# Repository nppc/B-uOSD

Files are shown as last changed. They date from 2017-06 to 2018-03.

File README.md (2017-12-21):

# Battery voltage microOSD v1.2
Very small and simple OSD for monitoring Battery voltage. It is useful for AIO micro cameras, FPV helmet etc.

The PCB is very small. Can be ordered at OshPark: https://oshpark.com/shared_projects/nvOy0lBm
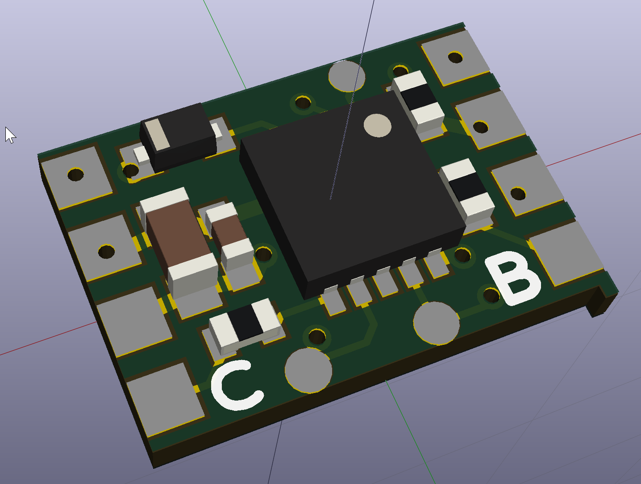
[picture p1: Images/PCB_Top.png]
Virtual PCB top

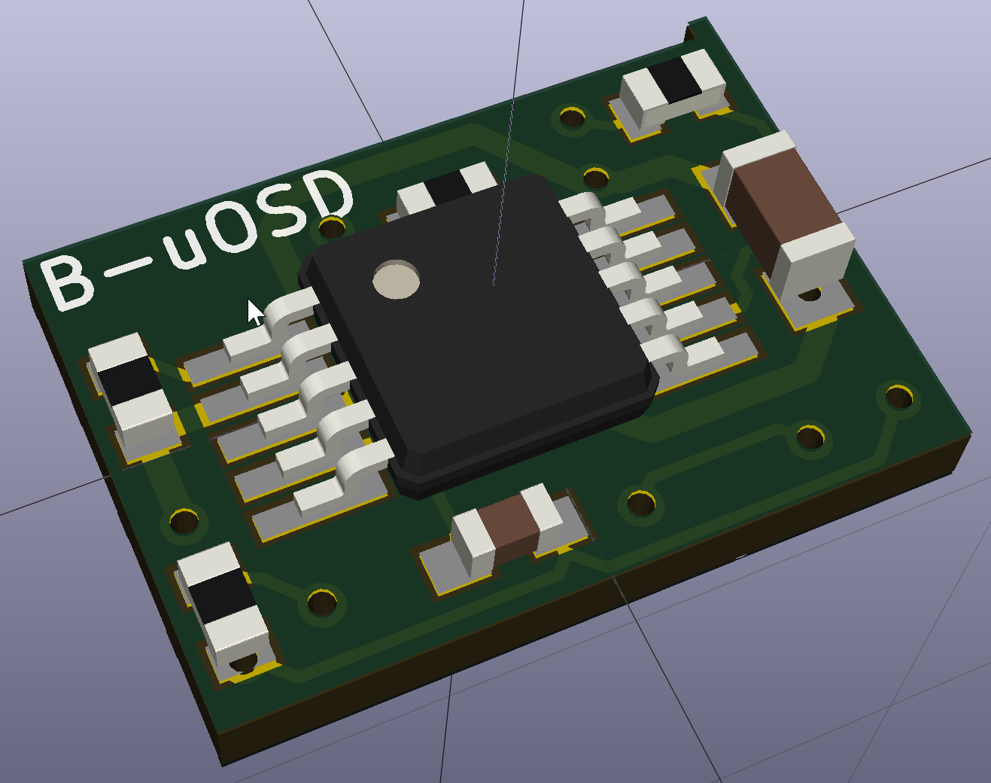
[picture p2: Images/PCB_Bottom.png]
Virtual PCB bottom


## Functionality
- Supports 1S-4S battery monitoring. (Changing onboard voltage divider can be extended for bigger batteries.)
- Adjustable text position.
- Shows current voltage and minimal detected voltage.
- Pilot name, Crosshair and timer.
- Voltage blinking if battery running low.
- Supply voltage 3.3-5.5v.
- Low supply current, no heat generation.
- It is very small size (8.8mm X 6mm).
- Virtually weights nothing.
- Configurable parameters via compiling.

It has minuses too.
- Due to small and slow mcu (no special mcu for signal generation) the OSD picture is not as stable as other bigger OSDs.
- No shadow around the symbols (not visible on white background). Planned it rhe future releases.

Discussion is here: https://www.rcgroups.com/forums/showthread.php?2985720-uOSD-World-smallest-micro-OSD

Some screenshots:
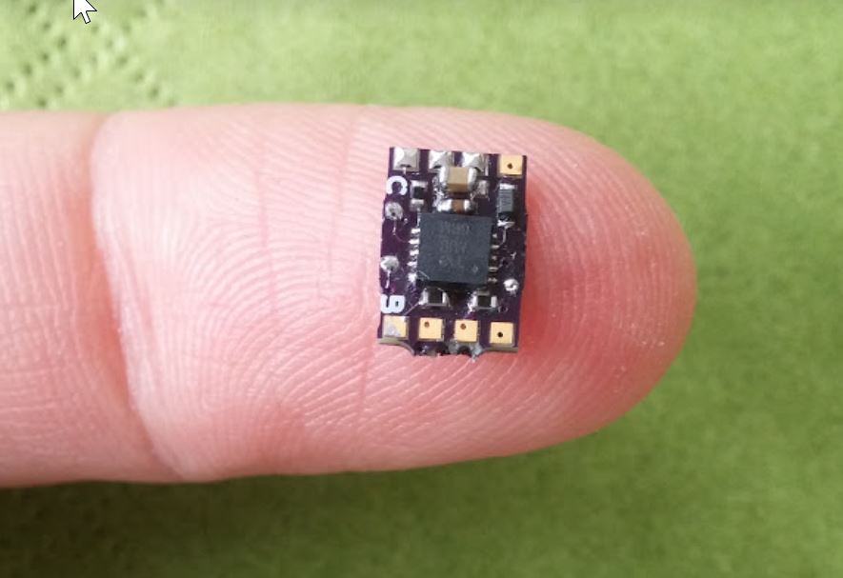
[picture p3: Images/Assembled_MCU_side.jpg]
Sample Double height

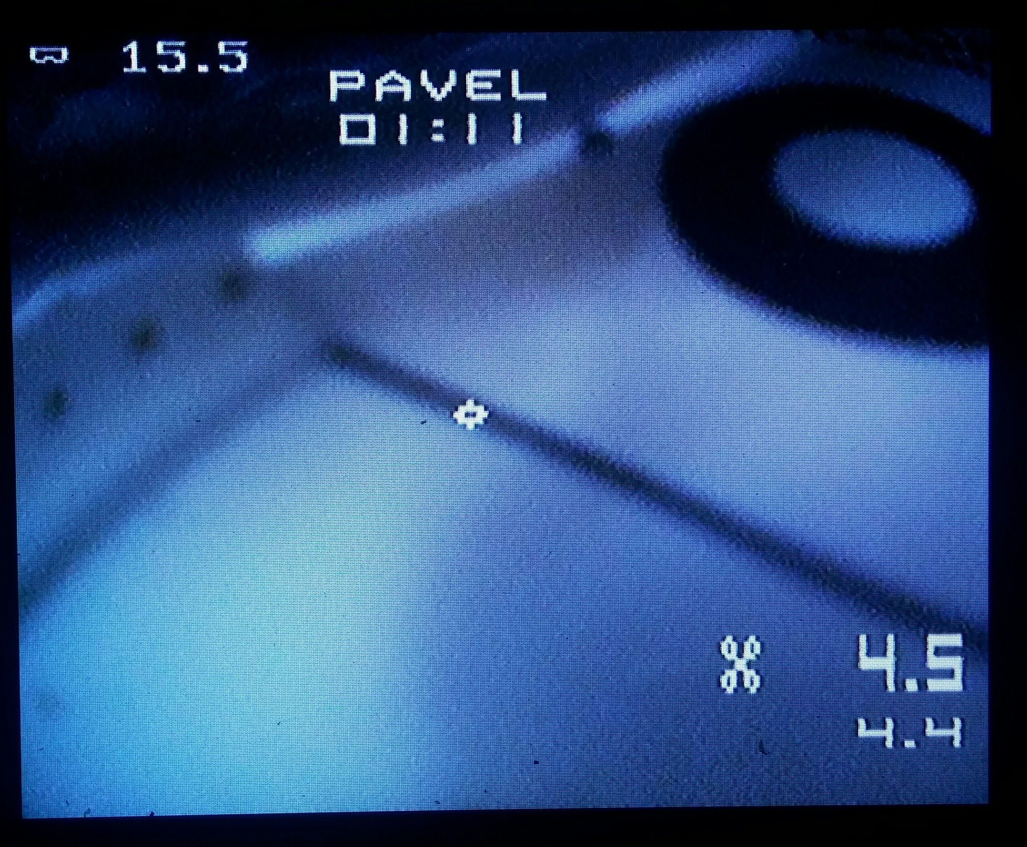
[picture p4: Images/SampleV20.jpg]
Sample V2.0


## Connection
There is many possibilities to use this OSD.
One example for 1S setup:
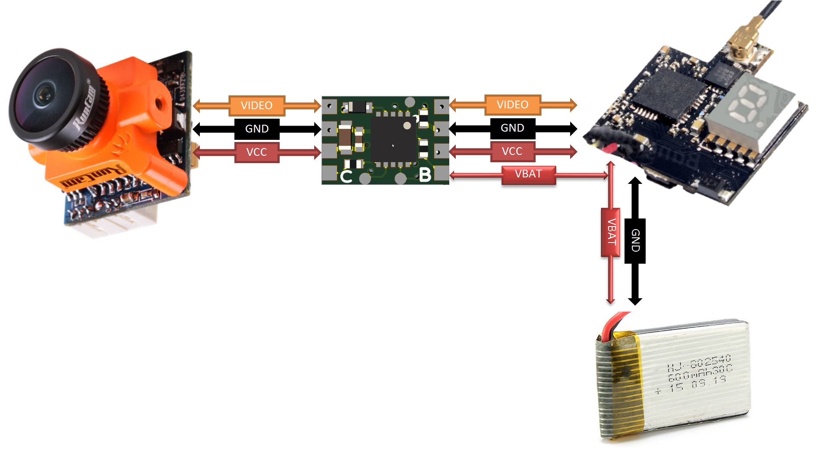
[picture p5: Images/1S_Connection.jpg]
Sample connection 1S


Another example for AIO combo camera/vtx 1S setup:
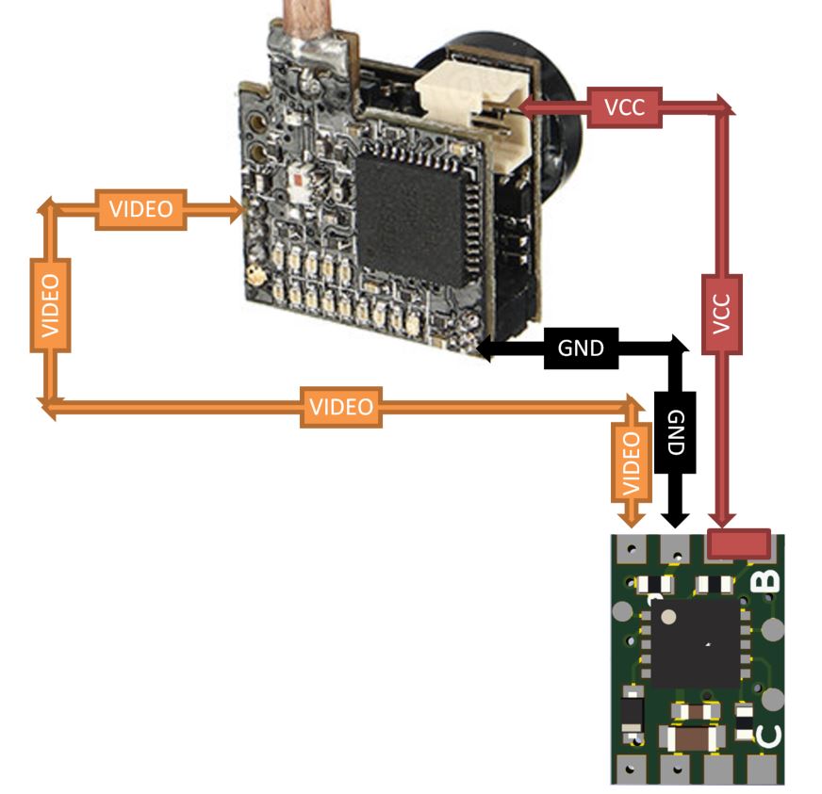
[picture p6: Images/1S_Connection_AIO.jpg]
Sample connection AIO 1S


## Compilation
To compile source files there is several options.
### Under Linux (even cheap OrangePi board will work)
Install `avra` and `git`
```
apt-get install avra git
```
Clone the project to any directory
```
git clone https://github.com/nppc/B-uOSD.git
```
Navigate to `Bin` directory
```
cd B-uOSD/Bin
```
And run `compile_linux.sh` script
```
./compile_linux.sh
```
Now you have .hex file.

### Under Windows
Project can be compiled with AVRASM2 (similar to avra on Linux) or with AVR Studio.

## Flashing
Use `avrdude` software and `USBASP` dongle for flashing microcontroller. 
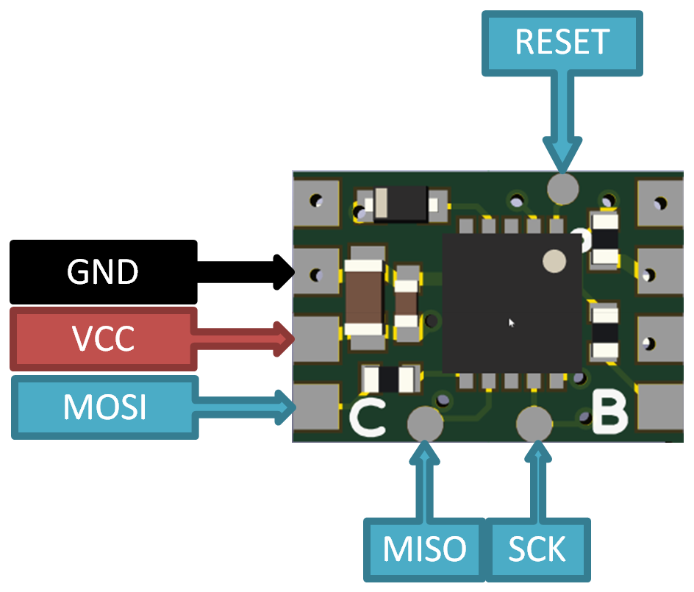
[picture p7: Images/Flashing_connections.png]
Connect for flashing

```
avrdude.exe -c usbasp -p t13 -P usb -B 4.0 -U flash:w:B-uOSD_vXX.hex:a
```

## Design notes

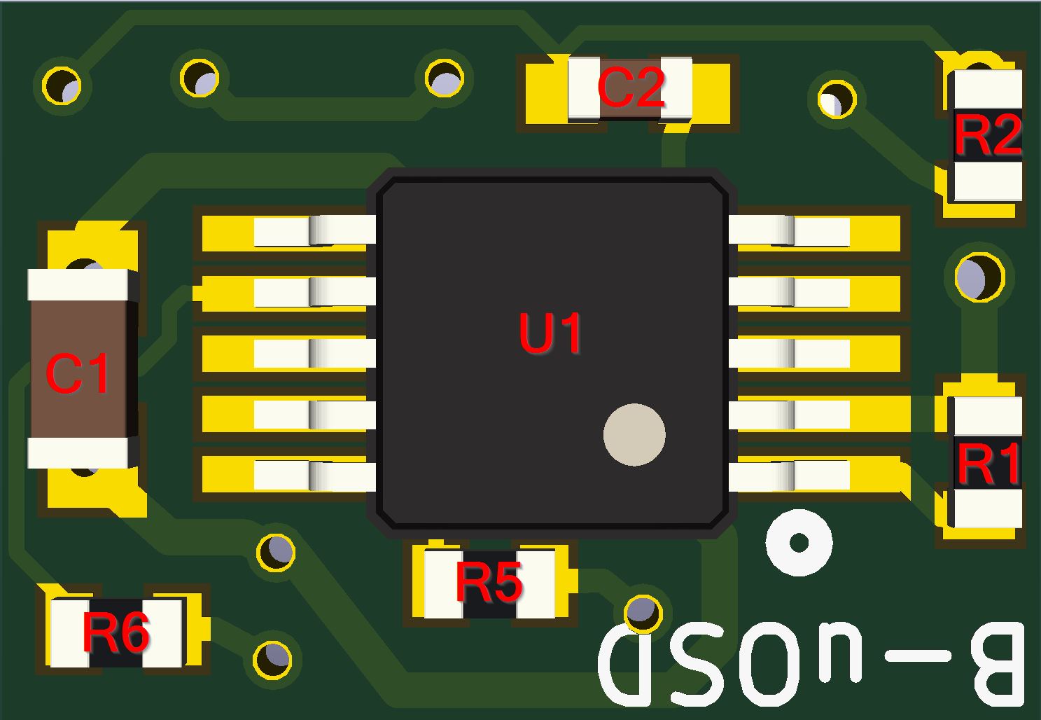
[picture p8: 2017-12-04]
Images/uOSD_V1_PCB2.jpg

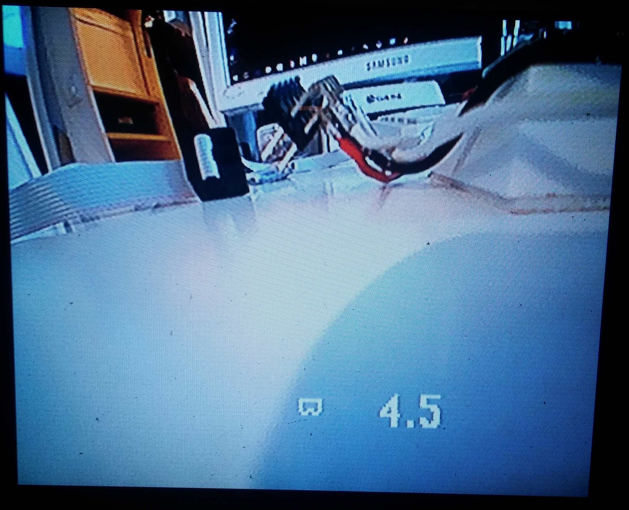
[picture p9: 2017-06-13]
Images/Sample_DG.jpg

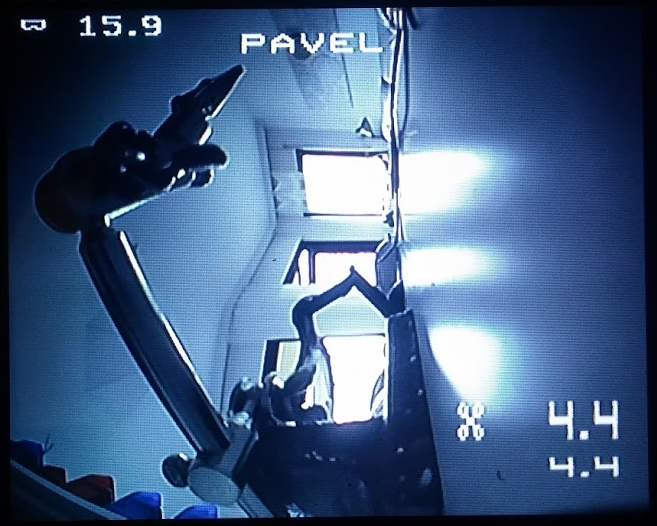
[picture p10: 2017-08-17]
Images/PILOTNAME.png

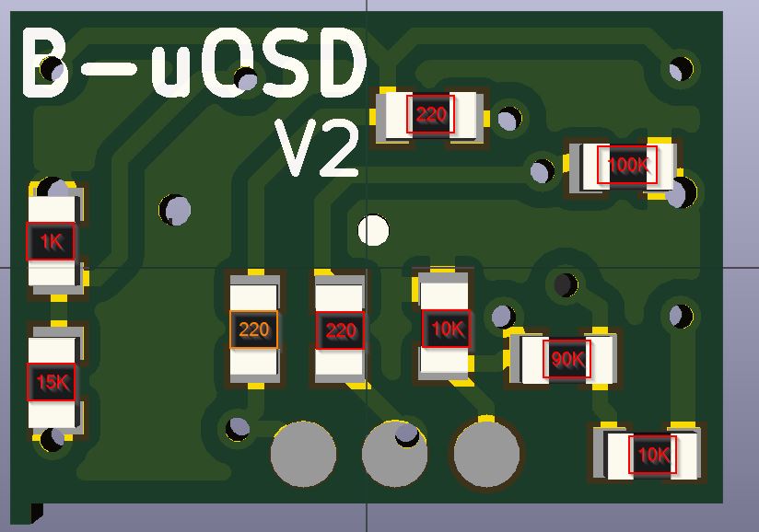
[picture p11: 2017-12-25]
Images/uOSD_V2_PCB_bottom.jpg

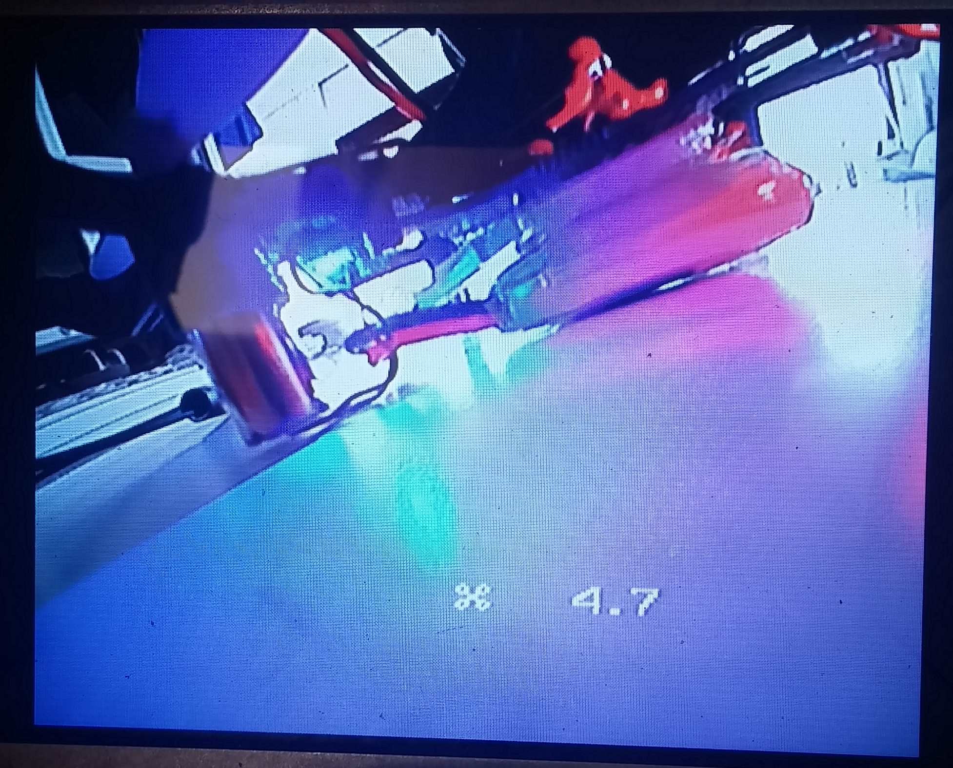
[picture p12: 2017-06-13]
Images/Sample_NC.jpg

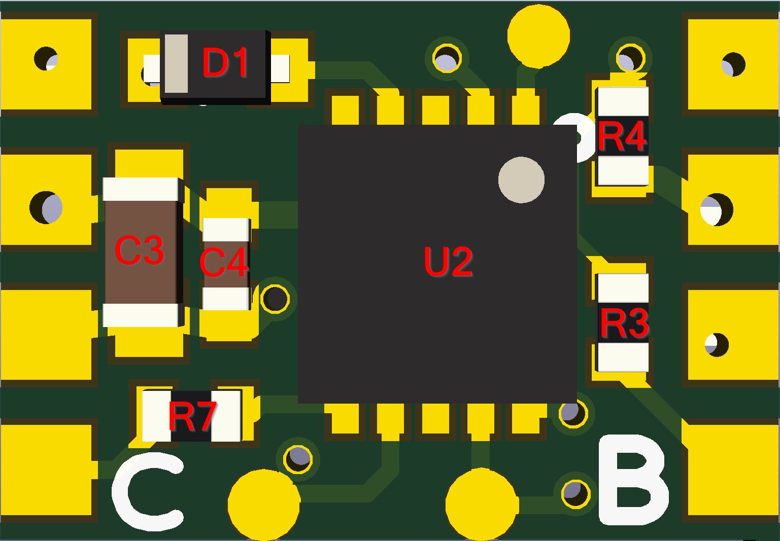
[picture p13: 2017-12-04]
Images/uOSD_V1_PCB.jpg

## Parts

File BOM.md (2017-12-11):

## Bill of Materials

Symbol | Component | Package | Mouser Part No
---- | ------------ | ------------ | ------------
U1 | LMH1980 | VSSOP-10 | 926-LMH1980MM/NOPB
U2 | ATTINY13A-MMU | MLF-10 | 556-ATTINY13A-MMU
R1 | 10K 1% | SMD 0402 | 603-AF0402FR-0710KL
R2 | 220 | SMD 0402 | 667-ERJ-2RKF2200X
R3 | 15K | SMD 0402 | 652-CR0402FX-1502GLF
R4 | 1K | SMD 0402 | 603-RC0402FR-071KL
R5 | 120 | SMD 0402 | 71-CRCW0402120RFKED
R6 | 120 | SMD 0402 | 71-CRCW0402120RFKED
R7 | 120 | SMD 0402 | 71-CRCW0402120RFKED
C1 | 100n | SMD 0402 | 710-885012105016
C2 | 100n | SMD 0402 | 710-885012105016
C3 | 10uf | SMD 0603 | 810-C1608X5R0J106M
C4 | 100n | SMD 0402 | 710-885012105016
D1 | 1N4148WT | SMD SOD-523 | 512-1N4148WT

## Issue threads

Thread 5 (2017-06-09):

Need something to do with voltage changes

nppc, 2017-06-09:
When voltage at the edge of changing its value on OSD, it's flicker too fast. Need to somehow reduce speed of updating voltage value...

Closed 2017-06-11.

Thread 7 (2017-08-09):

Min voltage should be sensed after main voltage stabilize

nppc, 2017-08-09:
Or as an alternative way, min voltage can reset every 10-20 seconds.

nppc, 2017-08-10:
Added some delay before ADC readings

Closed 2017-08-10.

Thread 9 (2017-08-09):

Bill of materials

brucesdad13, 2017-08-09:
Hello! Several of us would like to build one of these and have ordered PCBs from OSH Park. Can you offer a bill of materials of exactly which components we need? There's some confusion amongst us especially on the passives.

nppc, 2017-08-09:
Ok, will add it to the Readme. Do you need some quick answer now?

brucesdad13, 2017-08-09:
Yes a quick answer would be awesome. I'm on Mouser ordering components

nppc, 2017-08-09:
Added BOM.txt to the root folder,
If you have any questions, ask here...

nppc, 2017-08-10:
Added Mouser Part numbers

brucesdad13, 2017-08-11:
Thank you! Will be building next week and maybe have a PR or two if any ideas come up 😄 Otherwise thank you again Pavel this looks like such a cool project. Which AIO are you using?

nppc, 2017-08-11:
Thanks. :)
I tested it with this camera: https://www.banggood.com/Eachine-E010C-E010S-Spare-Part-p-1119217.html
But I think any camera will work. The simplicity of the schematic do not require to cut connectors on the camera. Just solder this B-uOSD to video pin.

brucesdad13, 2017-08-14:
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

Looks ok? 😄 Will try flashing next.

brucesdad13, 2017-08-14:
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

It's alive! 😀

nppc, 2017-08-14:
Ah, super! Looks nice. Congratulations! :)
What camera and vtx are you using?

brucesdad13, 2017-08-14:
This is the Boldclash F-02. It's a little on the heavy side but since comes already split it was the easiest to splice in the OSD. I ordered the exact camera you specified from banggood but it's on the slow boat. 😄

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

brucesdad13, 2017-08-14:
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

nppc, 2017-08-14:
Looks nice! How you solder? with solder station or somehow with reflow?

brucesdad13, 2017-08-15:
By hand with a little Zeny hot air and solder 2-in-1 station. 😄 I have two more to build sometime this week. Next I want to look at the code and see... can we fit pilot name?

brucesdad13, 2017-08-15:
Did some testing yesterday 😄 https://www.youtube.com/watch?v=hBjUEI953vA

nppc, 2017-08-15:
Heh... If you will look to the code, then you will see, that we have only 4 bytes (2 instructions) left free in FLASH. :)
So, with current MCU (1KB of FLASH) to fit pilot name is not possible.
But you can do custom bitmap (8*10 pixels) and use it instead of copter bitmap.

And... WOW! I impressed that you did a video!!!
What do you think, can you give me the fragment of your video to post it in the readme here?

brucesdad13, 2017-08-15:
I was wondering what if we removed the serial communications protocol and all the configuration was done compile-time? Yes I will happily give you the video clips.

nppc, 2017-08-15:
OK, please, create new issue, and then I will look how much space we will gain and what we can do with it...

brucesdad13, 2017-08-15:
Created 😄 It might be a bad idea on my part... Thanks Pavel!

Closed 2017-08-10.

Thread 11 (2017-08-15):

Feature Request: Pilot Name

brucesdad13, 2017-08-15:
Love this project! One idea occurred that perhaps, if it were possible to compile without the serial protocol, we could also have a compile-time option to include pilot name and/or target cursor on-screen.

nppc, 2017-08-16:
Ok. Interesting idea.
Currently we use 1020 bytes of FLASH from 1024. So, no space for new features.
I tried to make conditional compilation without CONFIG feature.
Now we use only 582 bytes of FLASH from 1024. Seems plenty of space! :)

nppc, 2017-08-16:
Alfa version of PILOTNAME feature is implemented.
`Branch try_name`
I can't test it, because I have no spare pcbs (ordered more boards OshPark)...

brucesdad13, 2017-08-17:
I will test ASAP! I have two PCBs left untouched of my original three. 😄Thanks again, Pavel!

brucesdad13, 2017-08-17:
So far so good. Will build a PCB ASAP.
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

nppc, 2017-08-17:
Thank you.
I got PCBs and assembled one.
Tested... Doesn't work. Need to fix small bug...

nppc, 2017-08-17:
Ok. Bug is fixed! :) Feel free to test working version... [:)[](url)](https://raw.githubusercontent.com/nppc/B-uOSD/try_name/Images/PILOTNAME.png)

nppc, 2017-08-25:
Implemented.
Draft in v1.3 (no official release), in v2.0 (will be released soon).

Closed 2017-08-25.

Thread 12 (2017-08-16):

Gray Backround of symbols

nppc, 2017-08-16:
If we remove CONFIG feature from OSD, then we have HW and SW resources to implement gray background under the text.

MicroMontis, 2017-11-29:
Or maybe gray shadow for the text?

nppc, 2017-11-29:
Shadow will be not possible to implement on this tiny MCU. It is too slow. If you look to the timing of code, then there is really no cycles left for other things. Only possible to make gray square background behind the symbol.

MicroMontis, 2017-11-29:
Ok, so lets leave this task for faster MCU's. Maybe Silabs BusyBee...?
Grey square backgroud is also OK.

nppc, 2017-11-29:
Heh... Could be in the future... I have currently so many other unfinished projects...

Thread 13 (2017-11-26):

Simplify circuit

Dakkaron, 2017-11-26:
This project is amazing! Great work so far!

I think the circuit can be simplified quite a bit though, by leavin out the LMH1980. It is the most expensive part in the design and it's work could be easily done by the ATTiny.

Just replace the LMH1980 with a clamping circuit and use the Analog Comparator included in the ATTiny together with a simple voltage divider to trigger an interrupt each time the clamped video signal dips unter 100mV. This then is the line sync signal. If the line sync signal happens at double speed a few times directly after another, that's the frame sync. On the software side that should not be much of a change.

A similar thing has been done here: https://www.rcgroups.com/forums/showthread.php?1473207-Diy-osd-%28Arduino-and-opensource%29

nppc, 2017-11-26:
Thank you.
Yes, mine first prototype version was planned with discrete components for video sync detection. But it comes in bigger size, than LMH solution.
If there will be interest, why not to make bigger, but cheaper version?

Dakkaron, 2017-11-26:
Is it really bigger? I just did a quick comparison in components. If you remove the LMH and its supporting components you loose 3 capacitors, 1 resistor and the LMH, but you need to put 1 capacitor, 3 resistors and 2 diodes. As far as I know, all these discrete components are aboutt the same size, so in the end you trade the LMH against two discrete components.

I am by far no expert in making little SMD boards, so I could be completely wrong. But if you use the built-in comparator in the ATTiny, this should work out to be smaller.

nppc, 2017-11-26:
Can you draw something? I have not much time at the moment. If you prepare schematic, I can make PCB. If you like, you can adjust firmware too. :)

Dakkaron, 2017-11-26:
I can try to do something in Kicad (I have never worked with it before, but I'd like to give it a try). If I can't get it to work, I'll send you a schematic.

I have done quite a bit with ATMegas, but only in C. I will have a look what I can do with the assembler code. I sadly don't have much possibility to test this all in hardware at the moment, because I am not near my hardware stash and won't be for a while... I hope, my schematic will make sense...

nppc, 2017-11-27:
Thanks! Schematic and some C code would be good. Then I can find time to make a draft of the new version.

brucesdad13, 2017-11-27:
Excited to see what you come up with! 👍

Dakkaron, 2017-11-28:
I currently don't have access to my hardware and testing stuff, but according to simulation, this here should do the job:

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

VIN is the video signal, V1 is the battery voltage (I simulated it with 3.3V and 5V and both seem to work fine, so I guess, there should be no problem with 1s batteries), AIN0 is pin 5 on the ATTiny13A and AIN1 is pin 6.

In the original circuit, R3 and R4 are realized with a potentiometer so the user can find the optimum values for the reference voltage on AIN0, but I think this can be hard-wired. According to the simulations I have done, these values should be ok, but it might be good to check that on a breadboard with a potentiometer first.

nppc, 2017-11-28:
Dakkaron! Thank you! Looks very promising!
Let me find the time to make a PCB... Maybe today... :)

nppc, 2017-11-28:
Full schematic - draft for V2 :)
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

Dakkaron, 2017-11-28:
Thanks for integrating that! Looks really good!
I wonder if maybe there should be a resistor between C2 and MISO/PB1. Or do you think the capacitor there is good enough to isolate MISO from VIDEO?

I have not been able to try this in hardware, so maybe it would be good to test this in hardware before integrating this. Especially the values for R7 and R8 should be verified in hardware, but if they are wrong changing the resistors out should be easy to do.

I am really looking forward to this! Thanks for the great work!

nppc, 2017-11-28:
I think AIN1 (PB1) don't need resistor. It is just an input to the MCU.
I'm just curious, do we really need 100 Ohm for R6 and R5? Looks they generating a lot of current?
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
Maybe 10K better?

Dakkaron, 2017-11-28:
@Resistor values: you are right, that's a mistake of mine. R6 should be 10K and R5 should be 100K.

@PB1: I thought, that maybe the resistor would be necessary so that the pin would still work as MISO for programming purposes, so that In Circuit Programming works. In your original schematic at https://github.com/nppc/B-uOSD/blob/master/KiCad/Schematic.pdf you secured each of the programming pins with a 120 Ohm resistor. I thought, that was for that purpose, so that the ATTiny / the programmer can drive the pins much stronger than the video signal can.

Dakkaron, 2017-11-28:
I did some more simulations and the values I found to work best with R6 being 10k and R5 being 100k are R7 as 60k and R3 as 40k. I simulated that with a VCC of 3-10V and everything seems to be stable. This way, power consumption should be quite minimal.

It takes a few cycles for the clamping mechanism to work, but the ATTiny-pins allow for a negative current of up to 1mA, so that should not be a problem. That only means that the OSD should wait for a few ms before engaging the interrupt.

nppc, 2017-11-28:
Ok! Thank you for the help! And I have good news :) As you said at the beginning...
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
I tried to put all higher components to one side, and resistors and 2 caps (low profile) on another...
If we look carefully, maybe both caps can be moved to the upper side.

Dakkaron, 2017-11-28:
This looks just cool! Thank you for your work!

nppc, 2017-11-28:
All tall components on one side. Now the pcb will fit between the PCBs of AIO FPV camera! :)
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

Dakkaron, 2017-11-28:
That's crazy! Amazing work! Thank you!

Dakkaron, 2017-11-28:
On the software side, what needs to be done is first, replace EXT_INT0 with ANA_COMP (this is all that is needed for horizontal sync). Vertical sync is a bit more complicated, I am not sure, what the best way to implement that is.

V-Sync is basically a H-Sync at double the frequency. A regular H-Sync happens every 63.5us for NTSC and every 64us for PAL. So if a Sync happen quicker than after 50us it must be a V-Sync.

So first you need a global flag bit, I'll call it is_h_sync and a timer that triggers after about 50us.
Whenever a sync happens, check if is_h_sync is set. If it is, treat the following sync as a H-Sync else as a V-Sync. Now unset the flag (set it to false) and reset the timer's counter register, so that it starts from the beginning.
If the timer interrupt triggers, set is_h_sync to true.

This is not perfectly accurate, it will always lag one line behind, but for this application that should not matter. Just don't draw to the first and last lines.

nppc, 2017-11-29:
Ok, sounds a good plan. Will later look to the code, when will have a time...

nppc, 2017-11-29:
Schematic can be finalized I think.
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
Maybe I can send the board to OSHPark, to have a prototype for debugging the code...

nppc, 2017-11-29:
Link to OSHPark PCB: [https://oshpark.com/shared_projects/5FUoUMnV](url)

Dakkaron, 2017-11-29:
This looks just cool! Thank you for your work! I'll probably order one of them aswell.
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
nppc, 2019-02-12:
Hi @vidzo!
So, 220 means 220 ohm. You should really play with R7 and R8 to get good sync results. So, R7 is 62K and R8 need to find a good value.
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

vidzo, 2019-02-12:
Hi @nppc,

Thanks for the reply. I was going quite another content this morning saying that I managed to work it out myself. I went through the schematic and datasheet with a multimeter I worked backwards. I learnt something in the process. But thank you.

I'm actually now at my next issue. I've connected it all to my usbasp but do I also need to power the board externally from a battery/source? It's currently not connecting  when using AVRDUDE. Also, I'm not really understanding how you compile e.g pilot name etc?

nppc, 2019-02-12:
Yes, the board should be powered. I think I powered it with supply power from programmer. And also re-check connections as this board is really tiny.
And check the error message you get. As it can be issue with the driver too.

Compiling your name is a bit tricky as mcu has not much flash memory.
You need to define letters (lines 50-54 in main.asm) what you will need. If letter appears twice, define it only ones.
Next you need to define order of characters in your name (line 287 in main.asm).
And in line 253 of the main.asm you should put length of your name (not longer than 10 chars).

If you want to enable/disable information on the screen or change the position of the element (like enable crosshair or disable timer, then you need to adjust lines 247-280. Comment out not needed block or uncomment it if you need it. And adjust column and line for the position of every block.
And at the end make sure that in line 247 you have correct quantity of data blocks (in current firmware there is 4 blocks: pilot name, timer, voltage and minimal voltage).

Hope this helps.

vidzo, 2019-02-12:
Thanks. I'll have to look into it all. I've connected all the pads and am powering it through the VCC of the programmer. Is this correct?

My confusion is to what to change and compile but I'm assuming that main.asm is edited through Notepad or a similar program? Thanks, will study it all and have another go.

nppc, 2019-02-12:
yes, VCC should be fine.
you can edit main.asm in notepad and then compile it as it described in readme.

vidzo, 2019-02-15:
Thanks nppc. I managed to connect to the chip (I forgot to add a jumper for power on the usbasp), compiled and flashed. I compiled a V2 hex (which has less code lines). However, after attaching to the AIO (LST S2) I am not getting anything on the display. I am using the top pin of the three on the VTX side of the AIO. This is meant to be signal. Is this correct? Also powering the Attiny13a through the ground and VBat pins on the VTX side. Are these the correct connections?

Also, when commenting in the main.asm file, when enabling the byte selection are supposed to comment in ;print name to;print name or ;print timer to print timer etc? Slightly confused by that

nppc, 2019-02-15:
You should compile it from **testANACOMPsync** branch (https://github.com/nppc/B-uOSD/tree/testANACOMPsync/VmOSD/VmOSDV2).

V is the video signal on uOSD board. It is top on both sides. I'm not sure where is the video on your AIO. On mine AIO it is the top one of three pin connector.

You can power the board with anything from 3 to 5 V on the +- pins. 5V from VTX is good. But I'm not sure what pin is Vbat on your VTX.

for commenting (disabling) lines you use ;.
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

vidzo, 2019-02-15:
Thanks nppc. I thinks that where o was going wrong; was compiling and flashing the incorrect branch. Thank you for the time spending answering my questions.

Commenting and uncomment is slightly different in Silverware firmware code so it threw me off.

vidzo, 2019-02-16:
Ok, managed to get it compiled and flashed. It seemed to be working but unfortunately I couldn't find some resistor values that worked. In light conditions the OSD jump and not end up in it's proper designated place on screen. In dark conditions, I got nothing. I tried the values that nppc began with, other suggested values and the problem persisted. I'm not sure if there's anything i could try so looks like I'll have to make V1

vidzo, 2019-02-19:
Sorry, I'm not willing to give up on this quite so easily! Is there anything that I can add code wise that may help?

nppc, 2019-03-04:
I don't see that code somehow can be adjusted as there is comparator interrupt is in use, that just catches the sync strobe from video signal. I think you still need to play with resistors divider as mentioned before. Maybe using POT instead of R8...

vidzo, 2019-03-04:
Hi nppc,

Yes, you're right. I have ordered some pots and will carry on testing once they arrive. I'm sure it'll all work just needs a bit more testing than anticipated

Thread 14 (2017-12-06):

License

Dakkaron, 2017-12-06:
What license are you using for the hardware? I see, the software is GPL, but what about the hardware?

What are your thoughts on Chinese vendors copying the project?

nppc, 2017-12-06:
Same for HW. If they will copy it and will have the name of uOSD or nppc
somewhere - I'm fine. :)

06 дек. 2017 г. 17:48 пользователь "Dakkaron" <notifications@github.com>
написал:

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

Closed 2018-08-28.

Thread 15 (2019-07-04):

PCB Files

ariefadha, 2019-07-04:
Any Eagle or Altium or Gerber files?

nppc, 2019-07-04:
There is KiCad project in Repo. KiCad is free. Just open it and there is a possibility to generate Gerbers.

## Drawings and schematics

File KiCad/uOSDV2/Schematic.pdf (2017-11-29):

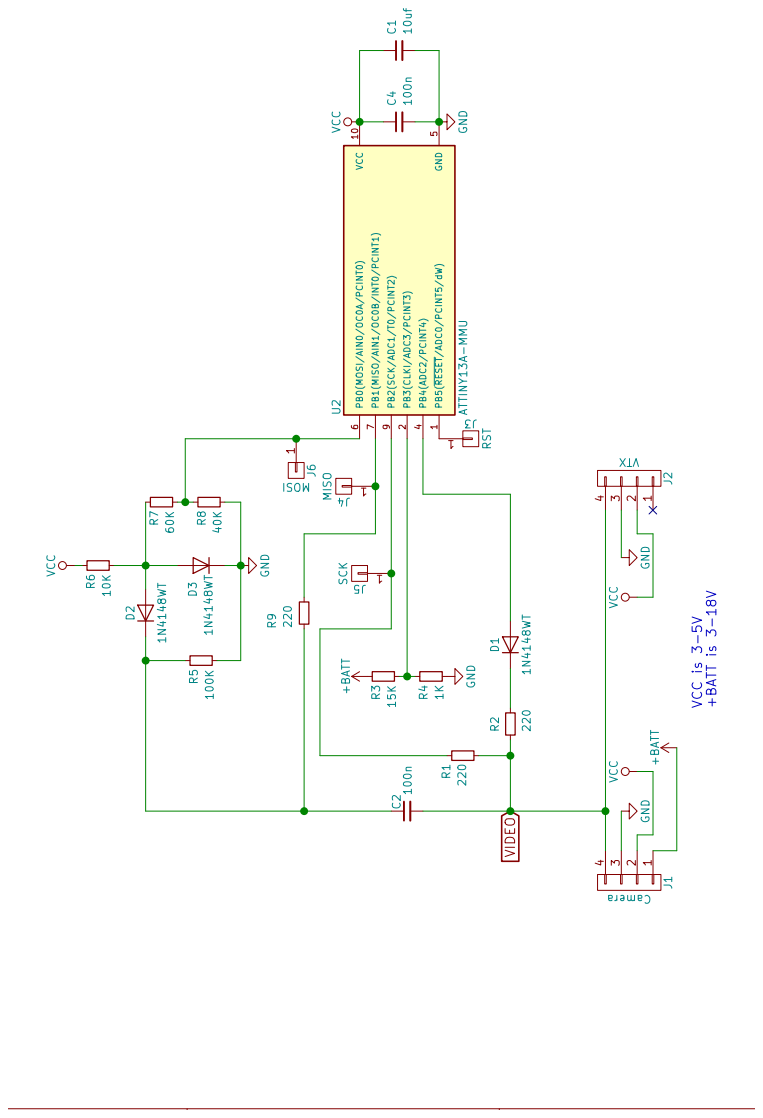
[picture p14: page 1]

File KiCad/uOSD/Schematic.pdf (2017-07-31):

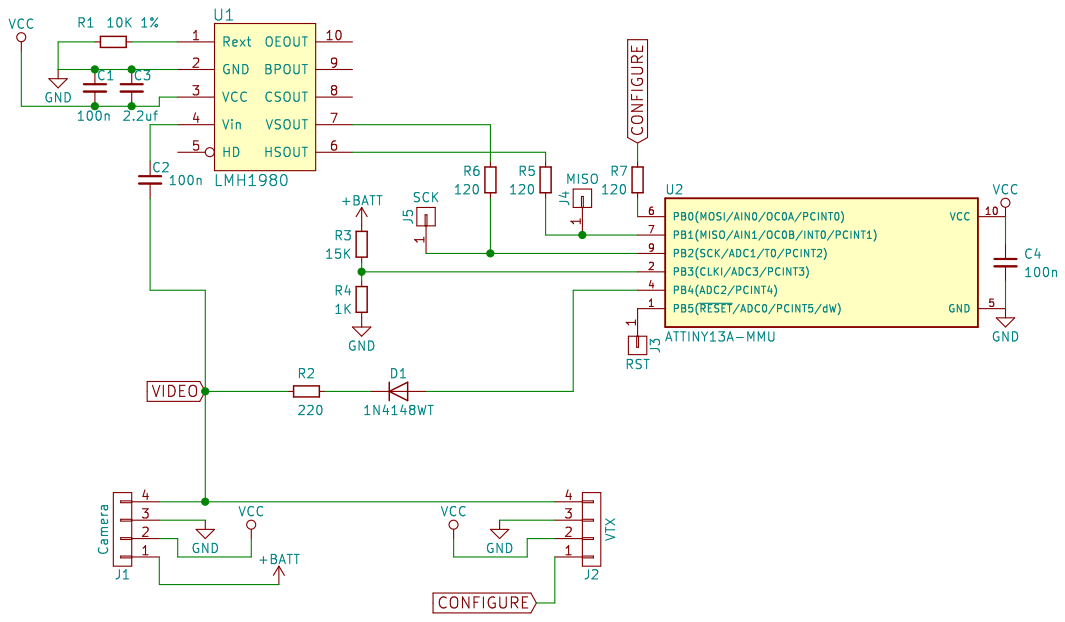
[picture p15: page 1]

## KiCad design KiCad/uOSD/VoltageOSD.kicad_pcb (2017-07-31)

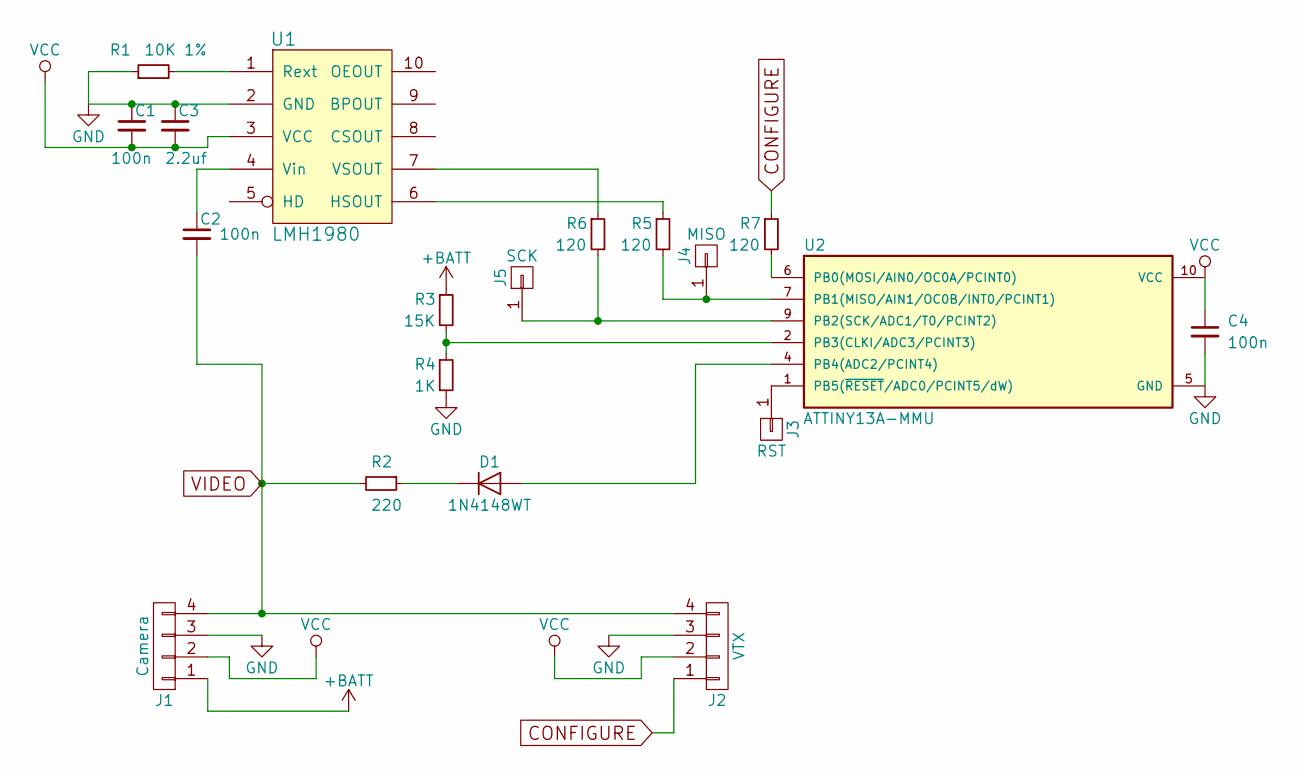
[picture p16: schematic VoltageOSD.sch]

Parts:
C1, C2, C4: 100n; C_0402_NoSilk
C3: 2.2uf; C_0603
D1: 1N4148WT; D_SOD-523
J1: Camera; 4pin_SMD_small
J2: VTX; 4pin_SMD_small
J3: RST; Prog_pad
J4: MISO; Prog_pad
J5: SCK; Prog_pad
R1: 10K 1%; R_0402_NoSilk
R2: 220; R_0402_NoSilk
R3: 15K; R_0402_NoSilk
R4: 1K; R_0402_NoSilk
R5, R6, R7: 120; R_0402_NoSilk
U1: LMH1980; MSOP-10_3x3mm_Pitch0.5mm
U2: ATTINY13A-MMU; MLF_10M1

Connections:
+BATT: J1.1, R3.1
CONFIGURE: J2.1, R7.1
GND: C1.1, C3.1, C4.2, J1.3, J2.3, R1.1, R4.2, U1.2 (GND), U2.5 (GND), U2.11
unnamed: C2.1, U1.4 (Vin)
unnamed: D1.1 (K), R2.1
unnamed: D1.2 (A), U2.4 (PB4(ADC2/PCINT4))
unnamed: J3.1, U2.1 (PB5(~RESET~/ADC0/PCINT5/dW))
unnamed: J4.1, R5.2, U2.7 (PB1(MISO/AIN1/OC0B/INT0/PCINT1))
unnamed: J5.1, R6.2, U2.9 (PB2(SCK/ADC1/T0/PCINT2))
unnamed: R1.2, U1.1 (Rext)
unnamed: R3.2, R4.1, U2.2 (PB3(CLKI/ADC3/PCINT3))
unnamed: R5.1, U1.6 (HSOUT)
unnamed: R6.1, U1.7 (VSOUT)
unnamed: R7.2, U2.6 (PB0(MOSI/AIN0/OC0A/PCINT0))
VCC: C1.2, C3.2, C4.1, J1.2, J2.2, U1.3 (VCC), U2.10 (VCC)
VIDEO: C2.2, J1.4, J2.4, R2.2

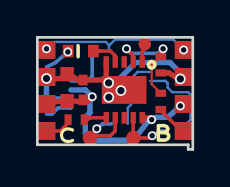
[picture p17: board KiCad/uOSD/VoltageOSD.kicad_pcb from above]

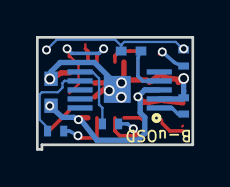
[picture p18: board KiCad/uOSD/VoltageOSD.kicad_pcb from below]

Board: 2 copper layers, 8.6 x 6.2 mm, 19 parts (7 on the bottom side), 16 nets.

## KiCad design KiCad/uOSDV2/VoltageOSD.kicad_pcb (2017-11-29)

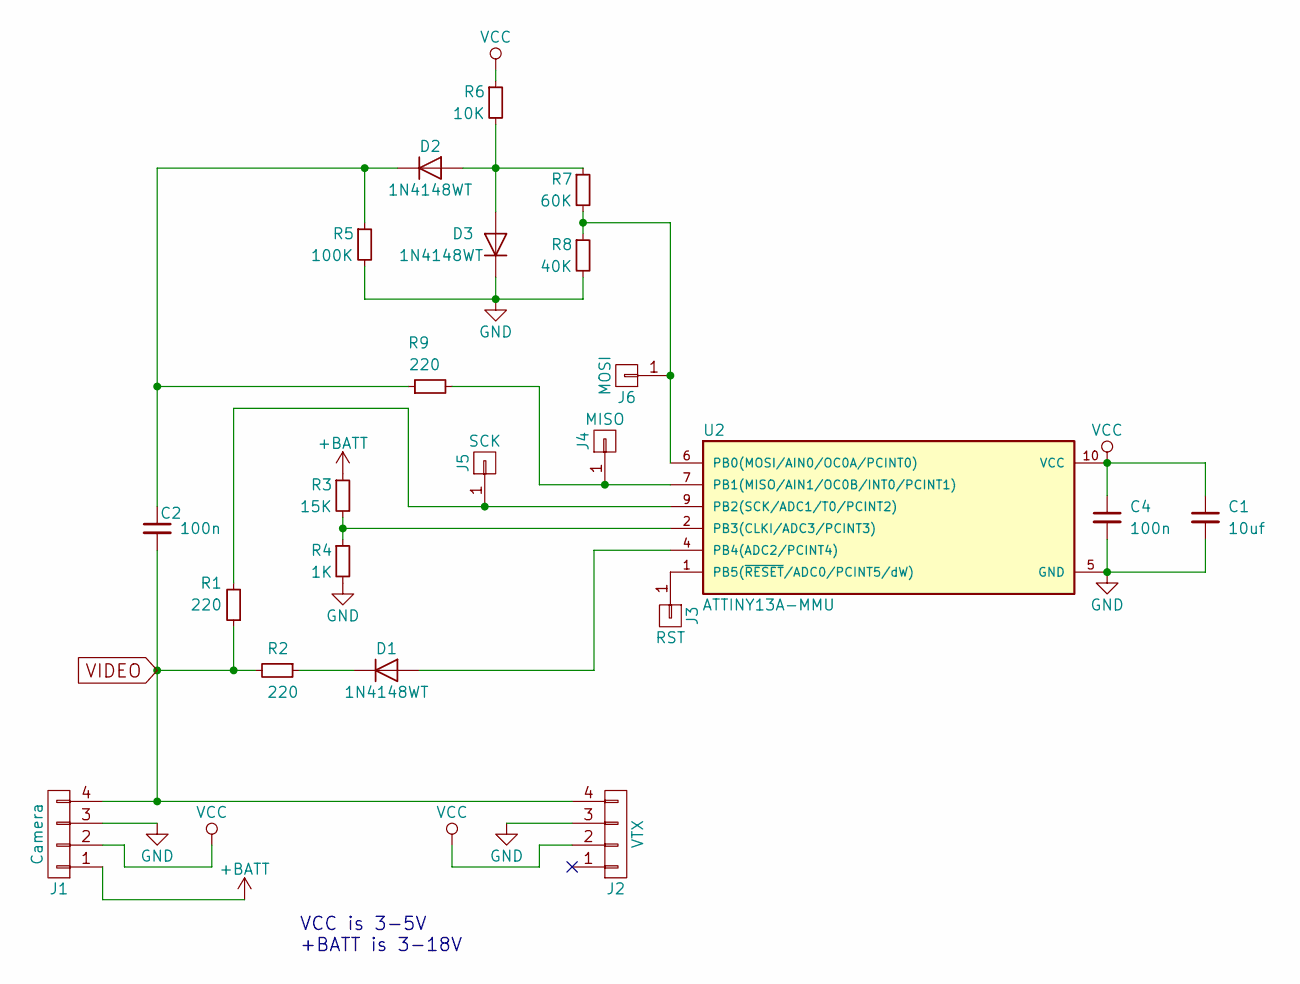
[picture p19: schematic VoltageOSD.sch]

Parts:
C1: 10uf; C_0402_NoSilk
C2, C4: 100n; C_0402_NoSilk
D1, D2, D3: 1N4148WT; D_SOD-523
J1: Camera; 4pin_SMD_small
J2: VTX; 4pin_SMD_small
J3: RST; Prog_pad
J4: MISO; Prog_pad
J5: SCK; Prog_pad
J6: MOSI; Prog_pad
R1, R2, R9: 220; R_0402_NoSilk
R3: 15K; R_0402_NoSilk
R4: 1K; R_0402_NoSilk
R5: 100K; R_0402_NoSilk
R6: 10K; R_0402_NoSilk
R7: 60K; R_0402_NoSilk
R8: 40K; R_0402_NoSilk
U2: ATTINY13A-MMU; MLF_10M1

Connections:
+BATT: J1.1, R3.1
GND: C1.2, C4.2, D3.1 (K), J1.3, J2.3, R4.2, R5.2, R8.2, U2.5 (GND)
unnamed: C2.1, D2.1 (K), R5.1, R9.1
unnamed: D1.1 (K), R2.1
unnamed: D1.2 (A), U2.4 (PB4(ADC2/PCINT4))
unnamed: D2.2 (A), D3.2 (A), R6.2, R7.1
unnamed: J3.1, U2.1 (PB5(~RESET~/ADC0/PCINT5/dW))
unnamed: J4.1, R9.2, U2.7 (PB1(MISO/AIN1/OC0B/INT0/PCINT1))
unnamed: J5.1, R1.2, U2.9 (PB2(SCK/ADC1/T0/PCINT2))
unnamed: J6.1, R7.2, R8.1, U2.6 (PB0(MOSI/AIN0/OC0A/PCINT0))
unnamed: R3.2, R4.1, U2.2 (PB3(CLKI/ADC3/PCINT3))
VCC: C1.1, C4.1, J1.2, J2.2, R6.1, U2.10 (VCC)
VIDEO: C2.2, J1.4, J2.4, R1.1, R2.2

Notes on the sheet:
VCC is 3-5V +BATT is 3-18V

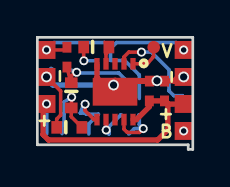
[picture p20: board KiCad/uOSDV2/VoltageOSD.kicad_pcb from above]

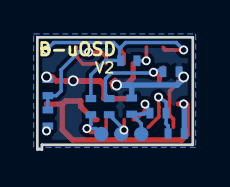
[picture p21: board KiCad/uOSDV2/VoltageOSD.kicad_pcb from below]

Board: 2 copper layers, 8.6 x 6.2 mm, 22 parts (12 on the bottom side), 13 nets.

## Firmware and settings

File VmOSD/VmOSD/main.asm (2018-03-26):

; * Author of B-uOSD is Pavel Palonen
; *
; * B-uOSD is free software: you can redistribute it and/or modify
; * it under the terms of the GNU General Public License as published by
; * the Free Software Foundation, either version 3 of the License, or
; * (at your option) any later version.
; *
; * B-uOSD is distributed WITHOUT ANY WARRANTY; without even the implied warranty of
; * MERCHANTABILITY or FITNESS FOR A PARTICULAR PURPOSE.  See the
; * GNU General Public License for more details.
; * this text shall be included in all
; * copies or substantial portions of the Software.
; *
; * See <http://www.gnu.org/licenses/>.

.include "tn13Adef.inc"

;***** BITMAP before voltage ******
;** uncomment one of the defines **
#define BITMAP_COPTER
;#define BITMAP_GOOGLES
;#define BITMAP_NONE
	

;---- END of configurable defines ----

 ; at 9.6mhz, 10 cycles = 1us
.EQU	OVERCLOCK_VAL	= 24		; How much to add to OSCCAL for overclocking
									; 8 is about 10.4 mhz.
									; 16 is about 11.5 mhz.
									; 24 is about 13 mhz.

									; PAL visible dots in 51.9us (498 cycles) or 166 dots at 9.6mhz
; PAL visible lines - 576 (interleased is half of that)

;************ CONFIGURATION ***************
; !!!!!This is user adjustable section!!!!!

; *** VOLTAGE SECTION
; Low Battery voltage value. Below this voltage, OSD voltage will start to blink
.EQU	LOW_BAT_VOLTAGE		= 30	; means 3.0 volts

; If your multimeter measurement will be different from OSD measurement, then correction can be made here.
; For example, if your multimeter shows, 11.5 volts, but OSD shows 11.7 volts, then enter here -2 (-0.2v).
.EQU	BAT_CORRECTION		= 0		; Signed int8 value for voltage readings correction


;*** PILOT NAME SYMBOLS
; Define here all characters, that will be printed as a pilot name.
#define SYM_P
#define SYM_A
#define SYM_V
#define SYM_E
#define SYM_L

;******************************************
; Show/Hide OSD elements configured 
; at the end of this file 
;******* END OF CONFIGURATION PART 1 *********


; If you did not changed hardware, then you don't need to change this...
.EQU	VOLT_DIV_CONST		= 186	; To get this number use formula (for 4S max): 
										; 4095/(Vmax*10)*8, where Vmax=(R1+R2)*Vref/R2, where Vref=1.1v 
										; and resistor values is from divider (15K/1K)
										; Vmax=(15+1)*1.1/1=17.6
										; 4095/(17.6*10)*8=186
										; For resistors 20K/1K constant will be 141 (max 5S battery). 
.EQU	BUFFER_LEN	 		= 10	; Length of the SRAM buffers fro text printing. - don't change this...

										
.EQU	VSOUT_PIN	= PB2	; Vertical sync pin
.EQU	HSOUT_PIN	= PB1	; Horizontal sync pin (Seems CSOUT pin is more reliable)
.EQU	CONF_PIN	= PB0	; Pin for device Configuration
.EQU	VBAT_PIN	= PB3	; Resistor divider (15K/1K) for voltage measurement (4S max)
.EQU	VIDEO_PIN	= PB4	; OSD Video OUT

.def	z0			=	r0
.def	z1			=	r1
.def	r_sreg		=	r2	; Store SREG register in interrupts
.def	tmp			=	r16
.def	tmp1		=	r17
.def	tmp2		=	r3
.def	itmp		=	r18	; variables to use in interrupts
.def	itmp1		=	r19	; variables to use in interrupts
.def	itmp2		=	r4	; variables to use in interrupts
.def	voltage		=	r5	; voltage in volts * 10 (dot will be printed in)
.def	voltage_min	=	r20	; Minimum detected voltage. voltage in volts * 10 (dot will be printed in)
.def	sym_line_nr	=	r6 	; line number of printed text (0 based)
.def	lowbat_cntr	=	r21	; counter for blinking voltage when it gets low
.def	sym_H_strch	=	r22	; value for symbol stretching
.def	sym_H_cntr	=	r7	; counter for symbol stretching
.def	adc_cntr	=	r23	; counter for ADC readings
.def	TV_lineL	=	r24 ; counter for TV lines Low byte. (don't change register mapping here)
.def	TV_lineH	=	r25 ; counter for TV lines High byte. (don't change register mapping here)
; Variables XL:XH, YL:YH, ZL:ZH are used in interrupts, so only use them in main code when interrupts are disabled
.def	adc_sumL	=	r8	; accumulated readings of ADC (sum of 64 values)
.def	adc_sumH	=	r9	; accumulated readings of ADC (sum of 64 values)
.def	osd_dot_pos	=	r10	; Position of the dot(.) in printed line. For numbers it is 2. For text it is 0.
.def	timer_flag	=	r11	; not 0 if we need to advance the timer
.def	timer_secs	=	r12	; Seconds of the timer
.def	timer_mins	=	r13	; Seconds of the timer

.DSEG
.ORG 0x60
; we need buffer in SRAM for printing numbers (total 4 bytes with dot)
buff_cur_volt:	.BYTE 6	; We have 6 symbols to print. Bitmap, space, voltage (nn.n)
buff_min_volt:	.BYTE 6	; We have 6 symbols to print. Bitmap, space, voltage (nn.n)
buff_timer:		.BYTE 5	; 5 symbols for timer 00:00
buff_cross:		.BYTE 1
buff_name:		.BYTE BUFFER_LEN
buff_data:		.BYTE BUFFER_LEN

.CSEG
.ORG 0
		rjmp RESET ; Reset Handler
		rjmp EXT_INT0 ; IRQ0 Handler
		reti	;rjmp PCINT_int ; PCINT0 Handler
		reti	;rjmp TIM0_OVF ; Timer0 Overflow Handler
		reti	;rjmp EE_RDY ; EEPROM Ready Handler
		reti	;rjmp ANA_COMP ; Analog Comparator Handler
		reti	;rjmp TIM0_COMPA ; Timer0 CompareA Handler
		reti	;rjmp TIM0_COMPB ; Timer0 CompareB Handler
		inc timer_flag	;rjmp WATCHDOG
		reti	;rjmp ADC ; ADC Conversion Handler

.include "font.inc"		; should be first line after interrupts vectors
.include "adc.inc"
.include "tvout.inc"
.include "timer.inc"

RESET:
		ldi tmp, low(RAMEND); Main program start
		out SPL,tmp ; Set Stack Pointer to top of RAM
		
		;init variables
		clr z0
		clr z1
		inc z1
		;clr adc_cntr		; couter for ADC readings. No need to initialize. Anyway we give some time for ADC to initialize all variables and states
		clr sym_line_nr		; first line of the char
		ldi lowbat_cntr, 254	; We want to start this counter to make a delay for voltage stabilizing
		;mov voltage_min, lowbat_cntr	; store big (255) value. Variable will be updated later
		mov sym_H_cntr, z0	; init variable. If 0 then we need update it.
		
		; change speed (ensure 9.6 mhz ossc)
		ldi tmp, 1<<CLKPCE	
		out CLKPR, tmp		; enable clock change
		out CLKPR, z0		; prescaler 1
		
		; Configure Video pin as OUTPUT (LOW)
		sbi	DDRB, VIDEO_PIN
		; Enable pullup on Configure Pin. We will enter configure mode if this pin will go LOW (by PCINT interrupt)
		sbi	PORTB, CONF_PIN
		
		;initialize INT0 
		; INT0 - H VIDEO Sync
		ldi tmp, 1<<ISC01 | 1<<ISC00 | 1<<SE	; falling edge, sleep mode enable
		out MCUCR, tmp
		ldi tmp, 1<<INT0 
		out GIMSK, tmp
				
		; Configure ADC
		; Internal 1.1Vref, ADC channel, 10bit ADC result
		ldi tmp, 1<<REFS0 | 1<<MUX0 | 1<<MUX1
		out ADMUX, tmp
		; normal mode (single conversion mode), 128 prescaler (about 75khz at 9.6mhz ossc).
		ldi tmp, 1<<ADEN | 1<<ADSC | 1<<ADPS2 | 1<<ADPS1 | 1<<ADPS0
		out ADCSRA, tmp
		; turn off digital circuity in analog pin
		sbi DIDR0, VBAT_PIN
		
		rcall OverclockMCU

		rcall FillPilotNameBuffer
		
		; fill CrossHair symbol SRAM Buffer
		ldi tmp, (symCross << 1)
		sts buff_cross, tmp

		; Wait for voltage stabilizing and ADC warmup
strt_wt:sbic ADCSRA, ADSC
		rjmp strt_wt
		; ADC is ready
		rcall ReadVoltage
		dec lowbat_cntr
		brne strt_wt	; read ADC 255 times
		; now our voltage and voltage_min is messed. Lets reset at least voltage_min.
		ldi voltage_min, 255
		
		rcall WDT_Start	; start timer
		
		sei ; Enable interrupts

main_loop:
		; in the main loop we can run only not timing critical code like ADC reading
		sleep
		cpi TV_lineL, 20		; first 20 lines is normally non-printing lines. Timing there is not critical
		cpc TV_lineH, z0
		brsh main_loop		; only read adc while first non-printing TV lines
		; read ADSC bit to see if conversion finished
		sbis ADCSRA, ADSC
		rcall ReadVoltage
		rcall Timer
		rjmp main_loop				
		
OverclockMCU:
		; overclock cpu from 9.6mhz
		; need to do it slowly
		in tmp2, OSCCAL
		ldi tmp, OVERCLOCK_VAL
OSC_ch:	inc tmp2
		out OSCCAL, tmp2
		dec tmp
		brne OSC_ch
		ret

FillPilotNameBuffer:
		ldi ZL, low(PilotNameCharsAddrs << 1)
		ldi ZH, high(PilotNameCharsAddrs << 1)
		ldi YL, low(buff_name)
		clr YH
		ldi tmp, BUFFER_LEN
FPNB1:	lpm tmp1, Z+
		st Y+, tmp1
		dec tmp
		brne FPNB1
		ret


;******* CONFIGURATION PART 2 *********		

; *** HOW many elements is showed on OSD. 
; For example, if you need to show 4 elements (Timer, Crosshair, Voltage and Min Voltage) 
; then EQU will look like this: OSDdataLen	= 4 * 8
.EQU	OSDdataLen	= 5 * 8	; 5 sections by 8 bytes each

; *** OSD Elements
; Comment unneeded blocks
OSDdata:
	; print Name (10 symbols max)
	.DB buff_name, 5		; buffer from where to print data, len of the printed text (6 for voltage)
	.DB 0, 0				; dot position from right (0 for text), reserved
	.DB 60, 1				; column to print and Symbol stretch (1 or 2)
	.DW 40					; line to print

	; print timer
	.DB buff_timer, 5		; buffer from where to print data, len of the printed text (6 for voltage)
	.DB 3, 0				; dot position from right (0 for text), reserved
	.DB 62, 1				; column to print and Symbol stretch (1 or 2)
	.DW 55					; line to print

	; print crosshair
	.DB buff_cross, 1		; buffer from where to print data, len of the printed text (6 for voltage)
	.DB 0, 0				; dot position from right (0 for text), reserved
	.DB 103, 1				; column to print and Symbol stretch (1 or 2)
	.DW 155					; line to print

	; print current voltage
	.DB buff_cur_volt, 6	; buffer from where to print data, len of the printed text (6 for voltage)
	.DB 2, 0				; dot position from right (0 for text), reserved
	.DB 140, 2				; column to print and Symbol stretch (1 or 2)
	.DW 240					; line to print

	; print min voltage
	.DB buff_min_volt, 6	; buffer from where to print data, len of the printed text (6 for voltage)
	.DB 2, 0				; dot position from right (0 for text), reserved
	.DB 140, 1				; column to print and Symbol stretch (1 or 2)
	.DW 270					; line to print
	

; *** PILOTNAME STRING
; maximum is 10 characters.	
; If you don't need Pilot Name on OSD, then comment out the .DB line (PilotNameCharsAddrs: label should not be commented)
PilotNameCharsAddrs:
	.DB symP<<1,symA<<1,symV<<1,symE<<1,symL<<1,symspc<<1

;*********** END OF CONFIGURATION *************

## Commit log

2017-06-04 change schematic for INT0. Add ASM project.
    [VoltageOSD.kicad_pcb, VoltageOSD.sch]
2017-06-05 Added ADC and software UART routines. Needs testing...
2017-06-05 UART routines tested and working. Baud is 19200
2017-06-06 TV out partially working, but only 7 lines of char printed.
    [VoltageOSD.sch]
2017-06-07 Discard using Timer for printing. It is just wasete of resources.
2017-06-08 Final Schematic and PCB (sent to OshPark)
    [VoltageOSD.kicad_pcb, VoltageOSD.sch]
2017-06-08 Fonts redesigned. Now they are variable width (experimental).
    [main.asm]
2017-06-08 Added Voltage correction functionality.
    [main.asm]
2017-06-08 Small syntax fix. Overclocked to 11.5mhz
    [main.asm]
2017-06-09 Some changes to the schematic values. Added space after bitmap.
    [VoltageOSD.sch]
2017-06-09 Low Battery blink implemented. Needs testing.
2017-06-12 Compatibility with cmd assemblers (AVRA, AVRASM2).
2017-06-28 Try fit code for printing second voltage
2017-06-28 Try fit code for printing second voltage (PART 2)
2017-06-28 Different font size for 1st and 2nd voltages. Code optimization for size.
2017-07-31 Adjusted schematic and PCB (not critical values)
    [VoltageOSD.kicad_pcb, VoltageOSD.sch]
2017-07-31 Success on 2 voltages project!
2017-08-01 Conditional compilation fix. New image added.
    [main.asm]
2017-08-09 Added BOM.txt draft
2017-08-10 Freeup some FLASH and startup delay for proper min voltage measuring
2017-08-10 BOM updated with Mouser part numbers
2017-08-11 Fix for min_voltage update at startup.
    [main.asm]
2017-08-16 fix compilation errors. PILOTNAME feature implemented.
    [main.asm]
2017-08-17 Fixed bug with PILOTNAME chars addressing
    [main.asm]
2017-08-17 Sample PILOTNAME image added
2017-08-25 V2.0 Full rework of code for better flexibility. Serial configuration is dropped.
    [main.asm]
2017-08-25 Fix small bug, adjust compile/flash script
    [main.asm]
2017-08-25 Crosshair added. Timer (experimental)
2017-08-25 Small fix, V2.0 is working!
    [main.asm]
2017-10-19 Fix small bug in ADC reading
2017-11-29 Preparing for the V2 PCB version without LMH IC
    [VoltageOSD.kicad_pcb, VoltageOSD.sch]
2017-12-11 Changed 2.2uf capacitor to 0402 10uf
2017-12-11 Changed 2.2uf capacitor to 0603 10uf
2017-12-25 V2 PCB componnts placement
2017-12-26 Added auto calibration for better video sync timing
